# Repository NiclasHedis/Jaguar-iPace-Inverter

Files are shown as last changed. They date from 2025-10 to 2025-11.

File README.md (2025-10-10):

# Jaguar-iPace-Inverter
Design of Opensource Logic boards to run the Jaguar iPace Inverter and Motors.

PCB Designs in Kicad 9 format.

Front inverter used in the iPace is acuallly a Vitesco EPF2.8+ :
https://vitesco-technologies.com/en/Home/Solutions/Products/High-Voltage-Inverter-(EPF2-8-)-en

Reverse engineering thread on the openinverter forum :
https://openinverter.org/forum/viewtopic.php?f=23&t=1210

Videos :
https://youtu.be/Kg5qWuOF9P8

10/10/25 : Add prelim front drive unit V1 board design (work in progress).

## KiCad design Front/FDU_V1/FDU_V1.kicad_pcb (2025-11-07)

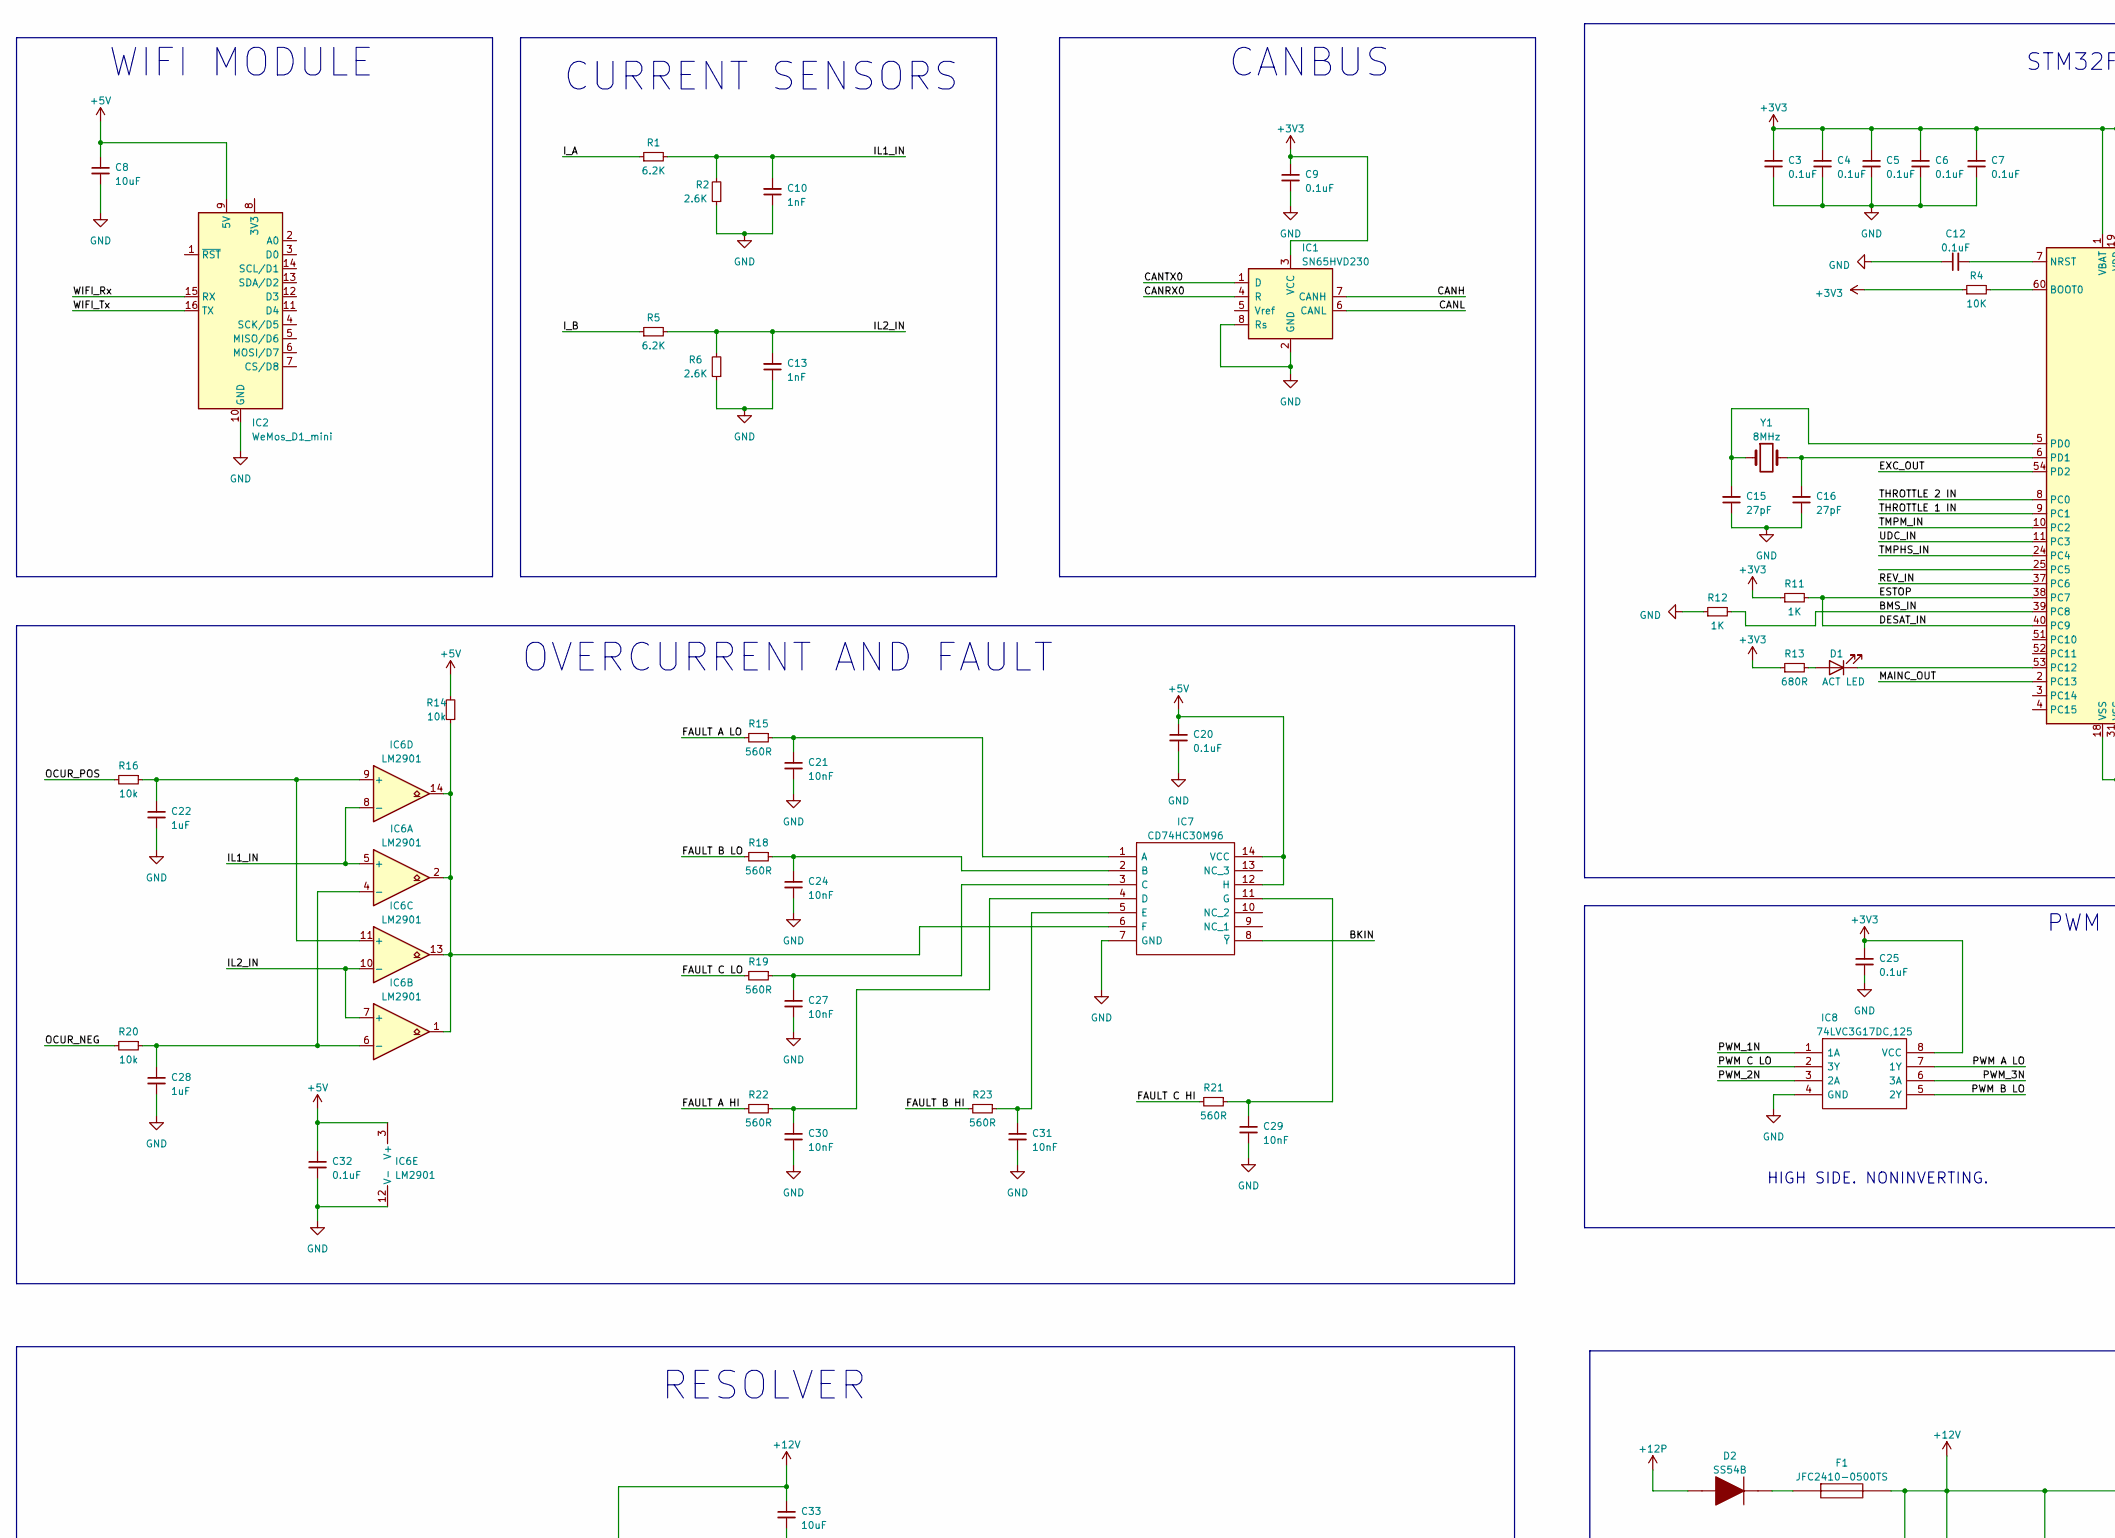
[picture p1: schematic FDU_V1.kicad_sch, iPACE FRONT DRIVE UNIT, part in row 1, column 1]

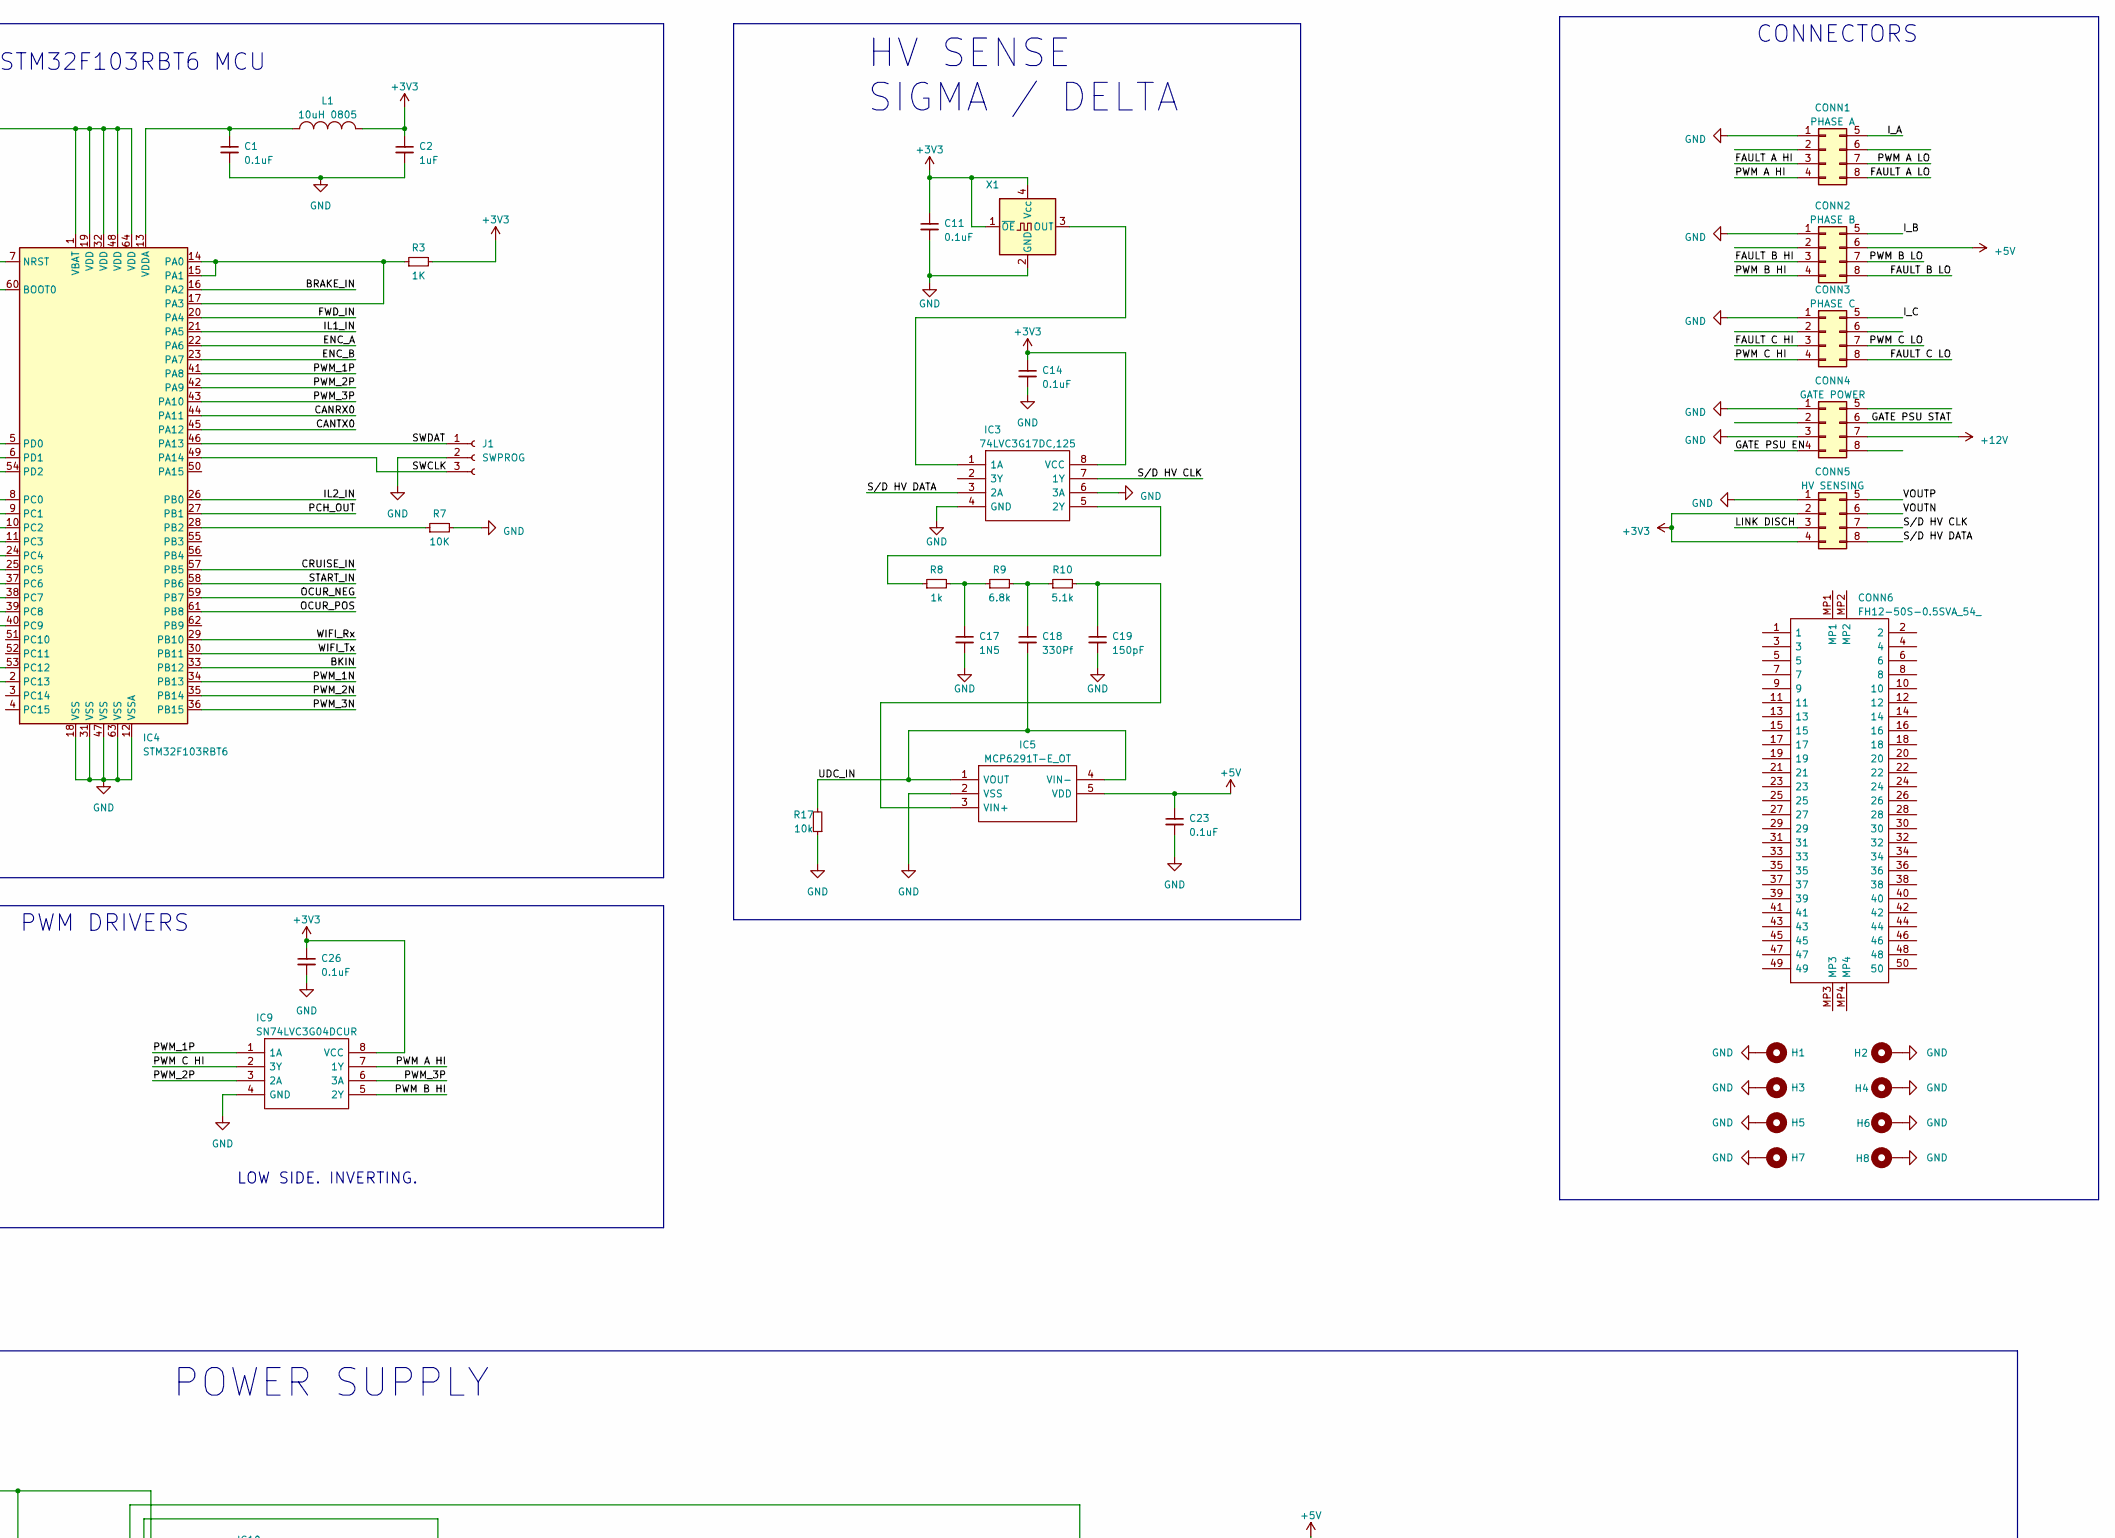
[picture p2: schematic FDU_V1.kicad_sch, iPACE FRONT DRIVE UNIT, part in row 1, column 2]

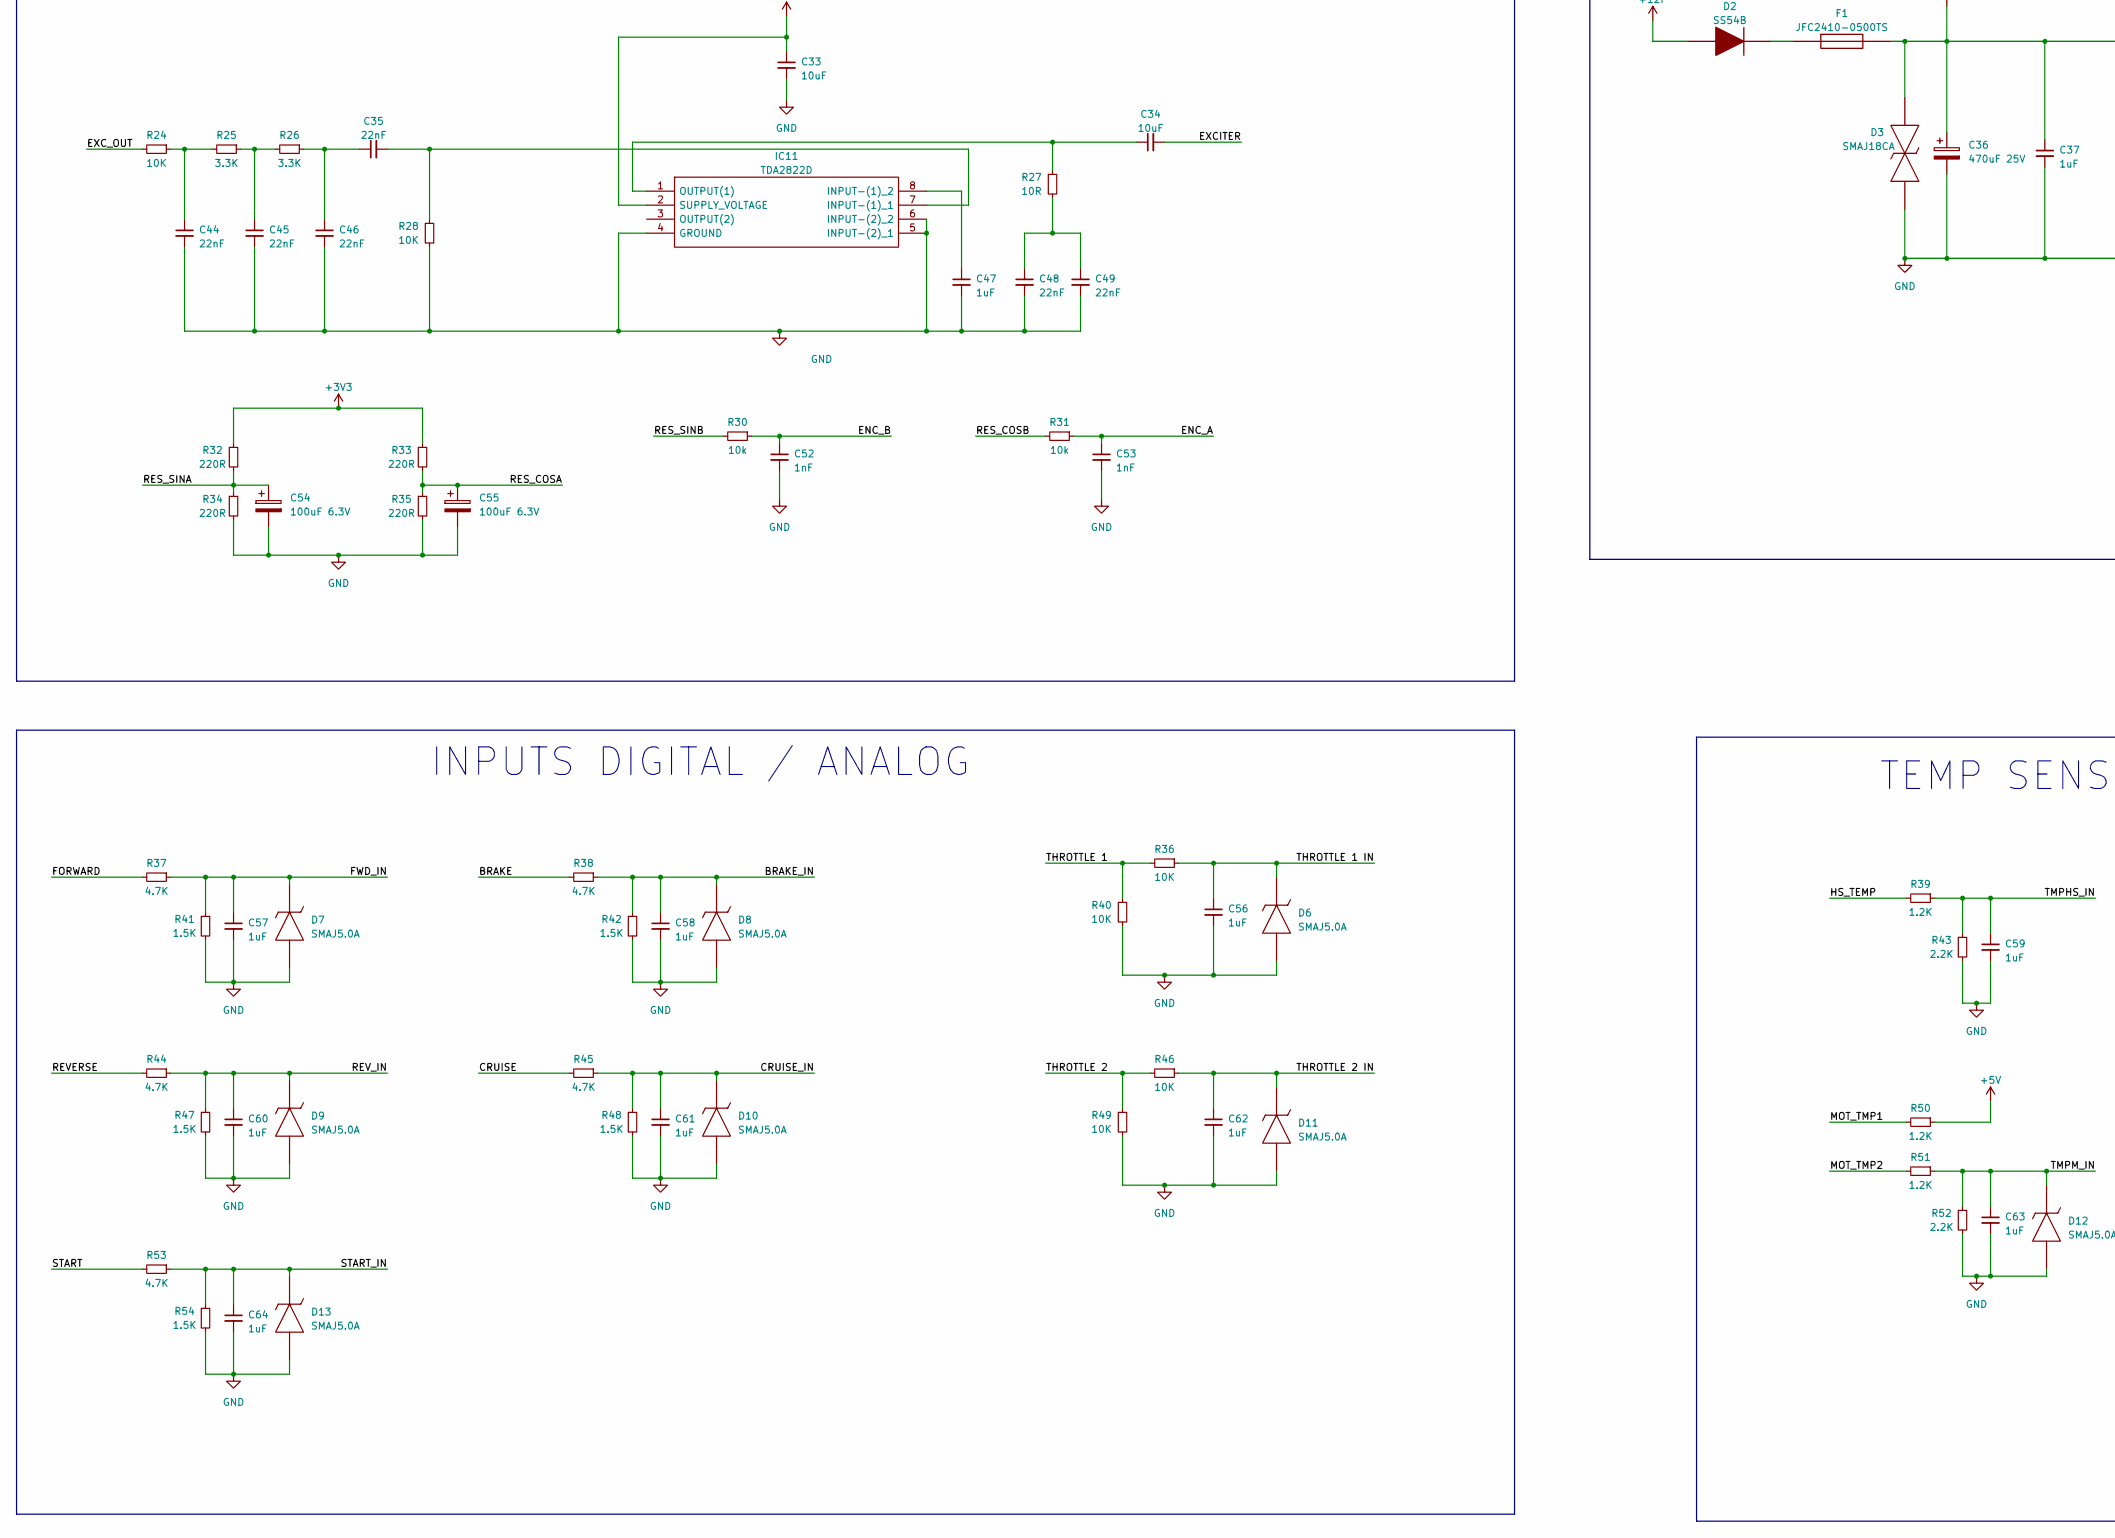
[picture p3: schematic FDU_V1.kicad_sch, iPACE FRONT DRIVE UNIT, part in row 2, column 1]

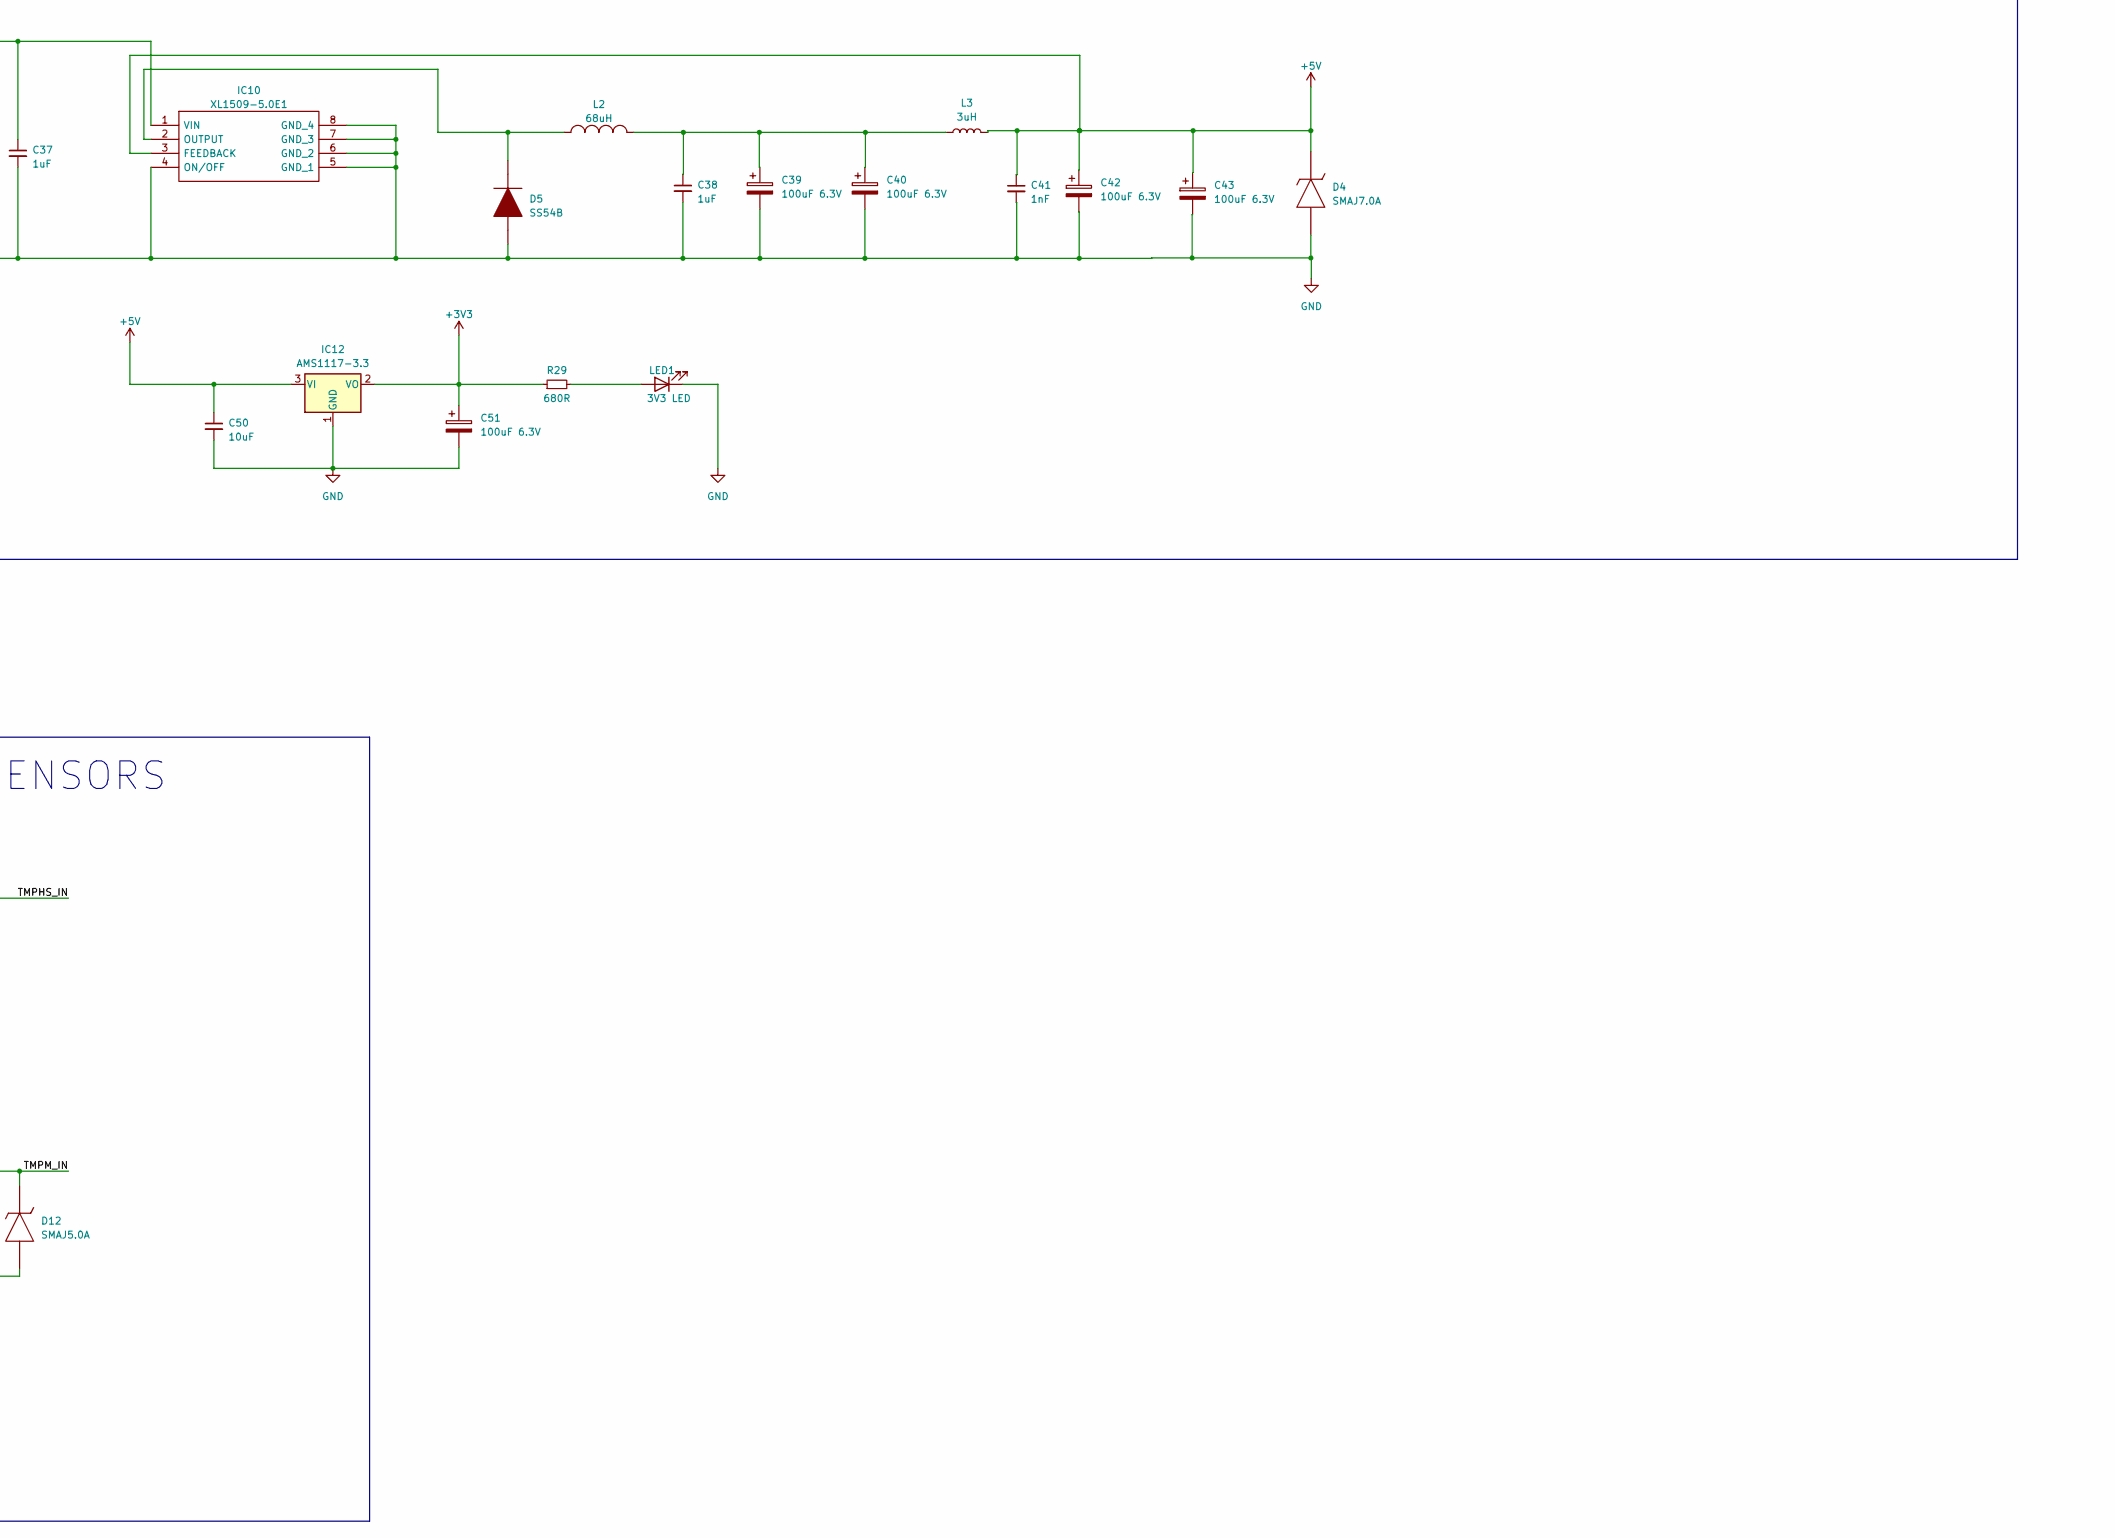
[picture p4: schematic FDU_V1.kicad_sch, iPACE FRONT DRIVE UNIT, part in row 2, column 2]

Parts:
C1, C3, C4, C5, C6, C7, C9, C11, C12, C14, C20, C23, C25, C26, C32: 0.1uF; C_0805_2012Metric
C2, C22, C28, C37, C38, C47, C56, C57, C58, C59, C60, C61, C62, C63, C64: 1uF; C_0805_2012Metric
C8, C33, C34, C50: 10uF; C_0805_2012Metric
C10, C13, C41, C52, C53: 1nF; C_0805_2012Metric
C15, C16: 27pF; C_0805_2012Metric
C17: 1N5; C_0805_2012Metric
C18: 330Pf; C_0805_2012Metric
C19: 150pF; C_0805_2012Metric
C21, C24, C27, C29, C30, C31: 10nF; C_0805_2012Metric
C35, C44, C45, C46, C48, C49: 22nF; C_0805_2012Metric
C36: 470uF 25V; CP_Elec_10x10
C39, C40, C42, C43, C51, C54, C55: 100uF 6.3V; CP_EIA-3528-15_AVX-H
CONN1: PHASE A; PinHeader_2x04_P2.54mm_Vertical
CONN2: PHASE B; PinHeader_2x04_P2.54mm_Vertical
CONN3: PHASE C; PinHeader_2x04_P2.54mm_Vertical
CONN4: GATE POWER; PinHeader_2x04_P2.54mm_Vertical
CONN5: HV SENSING; PinHeader_2x04_P2.54mm_Vertical
CONN6: FH12-50S-0.5SVA_54_; FH1250S05SVA54; Manufacturer_Part_Number FH12-50S-0.5SVA(54); Mouser Part Number 798-FH1250S0.5SVA54
D1: ACT LED; LED_0805_2012Metric
D2, D5: SS54B; DIOM5336X244N; Manufacturer_Part_Number SS54B
D3: SMAJ18CA; DIONM5127X229N; Manufacturer_Part_Number SMAJ18CA; Mouser Part Number 652-SMAJ18CA
D4: SMAJ7.0A; DIOM5026X229N; Manufacturer_Part_Number SMAJ7.0A; Mouser Part Number 576-SMAJ7.0A
D6, D7, D8, D9, D10, D11, D12, D13: SMAJ5.0A; DIOM5127X229N; Manufacturer_Part_Number SMAJ5.0A; Mouser Part Number 78-SMAJ5.0A
F1: JFC2410-0500TS; FUSC6126X280N; Manufacturer_Part_Number JFC2410-0500TS
H1: MountingHole; MountingHole_8.4mm_M8_Pad_Via
H2, H3, H4, H5, H6, H7, H8: MountingHole; MountingHole_8mm_ipace
IC1: SN65HVD230; SOIC-8_3.9x4.9mm_P1.27mm
IC2: WeMos_D1_mini; WEMOS_D1_mini_light
IC3, IC8: 74LVC3G17DC,125; SOP50P310X100-8N; Manufacturer_Part_Number 74LVC3G17DC,125; Mouser Part Number 771-LVC3G17DC125
IC4: STM32F103RBT6; LQFP-64_10x10mm_P0.5mm
IC5: MCP6291T-E_OT; SOT95P280X145-5N; Manufacturer_Part_Number MCP6291T-E/OT; Mouser Part Number 579-MCP6291T-E/OT
IC6: LM2901; SOIC-14_3.9x8.7mm_P1.27mm
IC7: CD74HC30M96; SOIC127P600X175-14N; Manufacturer_Part_Number CD74HC30M96; Mouser Part Number 595-CD74HC30M96
IC9: SN74LVC3G04DCUR; SOP50P310X90-8N; Manufacturer_Part_Number SN74LVC3G04DCUR; Mouser Part Number 595-SN74LVC3G04DCUR
IC10: XL1509-5.0E1; SOIC127P600X175-8N; Manufacturer_Part_Number XL1509-5.0E1
IC11: TDA2822D; SOIC127P600X175-8N; Manufacturer_Part_Number TDA2822D; Mouser Part Number 511-TDA2822D
IC12: AMS1117-3.3; SOT-223-3_TabPin2
J1: SWPROG; PinHeader_1x03_P2.54mm_Vertical
L1: 10uH 0805; L_0805_2012Metric
L2: 68uH; L_12x12mm_H8mm
L3: 3uH; L_10.4x10.4_H4.8
LED1: 3V3 LED; LED_0805_2012Metric
R1, R5: 6.2K; R_0805_2012Metric
R2, R6: 2.6K; R_0805_2012Metric
R3, R11, R12: 1K; R_0805_2012Metric
R4, R7, R24, R28, R36, R40, R46, R49: 10K; R_0805_2012Metric
R8: 1k; R_0805_2012Metric
R9: 6.8k; R_0805_2012Metric
R10: 5.1k; R_0805_2012Metric
R13, R29: 680R; R_0805_2012Metric
R14, R16, R17, R20, R30, R31: 10k; R_0805_2012Metric
R15, R18, R19, R21, R22, R23: 560R; R_0805_2012Metric
R25, R26: 3.3K; R_0805_2012Metric
R27: 10R; R_0805_2012Metric
R32, R33, R34, R35: 220R; R_0805_2012Metric
R37, R38, R44, R45, R53: 4.7K; R_0805_2012Metric
R39, R50, R51: 1.2K; R_0805_2012Metric
R41, R42, R47, R48, R54: 1.5K; R_0805_2012Metric
R43, R52: 2.2K; R_0805_2012Metric
X1: S3D4.000000B20F30T; Oscillator_SMD_EuroQuartz_XO32-4Pin_3.2x2.5mm
Y1: 8MHz; Crystal_SMD_5032-2Pin_5.0x3.2mm

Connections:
+3V3: C2.1, C3.1, C4.1, C5.1, C6.1, C7.1, C9.1, C11.1, C14.1, C25.1, C26.1, C51.1, CONN5.2, CONN5.4, IC1.3 (VCC), IC3.8 (VCC), IC4.1 (VBAT), IC4.19 (VDD), IC4.32 (VDD), IC4.48 (VDD), IC4.64 (VDD), IC8.8 (VCC), IC9.8 (VCC), IC12.2 (VO), L1.2, R3.2, R4.1, R11.1, R13.1, R29.1, R32.1, R33.1, X1.1 (~OE), X1.4 (Vcc)
+5V: C8.1, C20.1, C23.1, C32.1, C41.1, C42.1, C43.1, C50.1, CONN2.6, D4.1, IC2.9 (5V), IC5.5 (VDD), IC6.3 (V+), IC7.12 (H), IC7.14 (VCC), IC10.3 (FEEDBACK), IC12.3 (VI), L3.2, R14.2, R50.1; also elsewhere on the board
+12P: CONN6.28, CONN6.29, CONN6.30, CONN6.31, CONN6.32, CONN6.33, CONN6.34, CONN6.35, CONN6.36, CONN6.37, CONN6.38, CONN6.39, CONN6.40, CONN6.41, CONN6.42, CONN6.43, CONN6.44, CONN6.45, CONN6.46, CONN6.47, CONN6.48, CONN6.49, CONN6.50, D2.2
+12V: C33.1, C36.1, C37.1, CONN4.7, D3.1, F1.2, IC10.1 (VIN), IC11.2 (SUPPLY_VOLTAGE)
/BKIN: IC4.33 (PB12), IC7.8 (~Y)
/BMS_IN: IC4.39 (PC8), R12.2
/BRAKE: CONN6.14, R38.2
/BRAKE_IN: C58.1, D8.1, IC4.16 (PA2), R38.1, R42.1
/CANH: CONN6.1, IC1.7 (CANH)
/CANL: CONN6.2, IC1.6 (CANL)
/CANRX0: IC1.4 (R), IC4.44 (PA11)
/CANTX0: IC1.1 (D), IC4.45 (PA12)
/CRUISE: CONN6.22, R45.2
/CRUISE_IN: C61.1, D10.1, IC4.57 (PB5), R45.1, R48.1
/DESAT_IN: IC4.38 (PC7), IC4.40 (PC9), R11.2
/ENC_A: C53.1, IC4.22 (PA6), R31.1
/ENC_B: C52.1, IC4.23 (PA7), R30.1
/EXCA: C34.2, CONN6.17
/EXCB: CONN6.18; also elsewhere on the board
/EXC_OUT: IC4.54 (PD2), R24.2
/FAULT A HI: CONN1.3, R22.2
/FAULT A LO: CONN1.8, R15.2
/FAULT B HI: CONN2.3, R23.2
/FAULT B LO: CONN2.8, R18.2
/FAULT C HI: CONN3.3, R21.2
/FAULT C LO: CONN3.8, R19.2
/FORWARD: CONN6.7, R37.2
/FWD_IN: C57.1, D7.1, IC4.20 (PA4), R37.1, R41.1
/GATE PSU EN: CONN4.4
/GATE PSU STAT: CONN4.6
/HS_TEMP: R39.2
/IL1_IN: C10.2, IC4.21 (PA5), IC6.5 (+), IC6.8 (-), R1.2, R2.2
/IL2_IN: C13.2, IC4.26 (PB0), IC6.7 (+), IC6.10 (-), R5.2, R6.2
/I_A: CONN1.5, R1.1
/I_B: CONN2.5, R5.1
/I_C: CONN3.5
/LINK DISCH: CONN5.3
/MAINC_OUT: IC4.2 (PC13)
/MOT_TMP1_1: CONN6.9, R50.2
/MOT_TMP1_2: CONN6.10, R51.2
/MOT_TMP2_1: CONN6.11; also elsewhere on the board
/MOT_TMP2_2: CONN6.12; also elsewhere on the board
/OCUR_NEG: IC4.59 (PB7), R20.2
/OCUR_POS: IC4.61 (PB8), R16.2
/PCH_OUT: IC4.27 (PB1)
/PWM A HI: CONN1.4, IC9.7 (1Y)
/PWM A LO: CONN1.7, IC8.7 (1Y)
/PWM B HI: CONN2.4, IC9.5 (2Y)
/PWM B LO: CONN2.7, IC8.5 (2Y)
/PWM C HI: CONN3.4, IC9.2 (3Y)
/PWM C LO: CONN3.7, IC8.2 (3Y)
/PWM_1N: IC4.34 (PB13), IC8.1 (1A)
/PWM_1P: IC4.41 (PA8), IC9.1 (1A)
/PWM_2N: IC4.35 (PB14), IC8.3 (2A)
/PWM_2P: IC4.42 (PA9), IC9.3 (2A)
/PWM_3N: IC4.36 (PB15), IC8.6 (3A)
/PWM_3P: IC4.43 (PA10), IC9.6 (3A)
/RES_COSA: C55.1, CONN6.21, R33.2, R35.1
/RES_COSB: CONN6.20, R31.2
/RES_SINA: C54.1, CONN6.23, R32.2, R34.1
/RES_SINB: CONN6.24, R30.2
/REVERSE: CONN6.8, R44.2
/REV_IN: C60.1, D9.1, IC4.37 (PC6), R44.1, R47.1
/START: CONN6.3, R53.2
/START_IN: C64.1, D13.1, IC4.58 (PB6), R53.1, R54.1
/SWCLK: IC4.49 (PA14), J1.3
/SWDAT: IC4.46 (PA13), J1.1
/S/D HV CLK: CONN5.7, IC3.7 (1Y)
/S/D HV DATA: CONN5.8, IC3.3 (2A)
/THROTTLE 1: CONN6.15, R36.2, R40.1
/THROTTLE 1 IN: C56.1, D6.1, IC4.9 (PC1), R36.1
/THROTTLE 2: CONN6.16, R46.2, R49.1
/THROTTLE 2 IN: C62.1, D11.1, IC4.8 (PC0), R46.1
/TMPHS_IN: C59.1, IC4.24 (PC4), R39.1, R43.1
/UDC_IN: C18.2, IC4.11 (PC3), IC5.1 (VOUT), IC5.4 (VIN-), R17.2
/VOUTN: CONN5.6
/VOUTP: CONN5.5
/WIFI_Rx: IC2.15 (RX), IC4.29 (PB10)
/WIFI_Tx: IC2.16 (TX), IC4.30 (PB11)
/WTR_TMP1: CONN6.5; also elsewhere on the board
/WTR_TMP2: CONN6.6; also elsewhere on the board
GND: C1.2, C2.2, C3.2, C4.2, C5.2, C6.2, C7.2, C8.2, C9.2, C10.1, C11.2, C12.1, C13.1, C14.2, C15.1, C16.1, C17.2, C19.2, C20.2, C21.2, C22.2, C23.2, C24.2, C25.2, C26.2, C27.2, C28.2, C29.2, C30.2, C31.2, C32.2, C33.2, C36.2, C37.2, C38.2, C39.2, C40.2, C41.2, C42.2, C43.2, C44.2, C45.2, C46.2, C47.2, C48.2, C49.2, C50.2, C51.2, C52.2, C53.2, C54.2, C55.2, C56.2, C57.2, C58.2, C59.2, C60.2, C61.2, C62.2, C63.2, C64.2, CONN1.1, CONN2.1, CONN3.1, CONN4.1, CONN4.3, CONN5.1, D3.2, D4.2, D5.2, D6.2, D7.2, D8.2, D9.2, D10.2, D11.2, D12.2, D13.2, H1.1, H2.1, H3.1, H4.1, H5.1, H6.1, H7.1, H8.1, IC1.2 (GND), IC1.8 (Rs), IC2.10 (GND), IC3.4 (GND), IC3.6 (3A), IC4.12 (VSSA), IC4.18 (VSS), IC4.31 (VSS), IC4.47 (VSS), IC4.63 (VSS), IC5.2 (VSS), IC6.12 (V-), IC7.7 (GND), IC8.4 (GND), IC9.4 (GND), IC10.4 (ON/OFF), IC10.5 (GND_1), IC10.6 (GND_2), IC10.7 (GND_3), IC10.8 (GND_4), IC11.4 (GROUND), IC11.5 (INPUT-(2)_1), IC11.6 (INPUT-(2)_2), IC12.1 (GND), J1.2, LED1.1 (K), R2.1, R6.1, R7.2, R12.1, R17.1, R28.2, R34.2, R35.2, R40.2, R41.2, R42.2, R43.2, R47.2, R48.2, R49.2, R52.2, R54.2, X1.2 (GND); also elsewhere on the board
unnamed: C17.1, R8.2, R9.1
unnamed: C18.1, R9.2, R10.1
unnamed: C35.1, C46.1, R26.1
unnamed: C38.1, C39.1, C40.1, L2.2, L3.1
unnamed: C44.1, R24.1, R25.2
unnamed: C45.1, R25.1, R26.2
unnamed: C48.1, C49.1, R27.2
unnamed: D1.2 (A), R13.2
unnamed: D1.1 (K), IC4.53 (PC12)
unnamed: D2.1, F1.1
unnamed: IC3.1 (1A), X1.3 (OUT)
unnamed: IC3.5 (2Y), R8.1
unnamed: IC4.60 (BOOT0), R4.2
unnamed: C12.2, IC4.7 (NRST)
unnamed: IC4.14 (PA0), IC4.15 (PA1), IC4.17 (PA3), R3.1
unnamed: IC4.28 (PB2), R7.1
unnamed: C15.2, IC4.5 (PD0), Y1.1
unnamed: C16.2, IC4.6 (PD1), Y1.2
unnamed: C1.1, IC4.13 (VDDA), L1.1
unnamed: C19.1, IC5.3 (VIN+), R10.2
unnamed: C28.1, IC6.4 (-), IC6.6 (-), R20.1
unnamed: C22.1, IC6.9 (+), IC6.11 (+), R16.1
unnamed: C21.1, IC7.1 (A), R15.1
unnamed: C24.1, IC7.2 (B), R18.1
unnamed: C27.1, IC7.3 (C), R19.1
unnamed: C30.1, IC7.4 (D), R22.1
unnamed: C31.1, IC7.5 (E), R23.1
unnamed: IC6.1, IC6.2, IC6.13, IC6.14, IC7.6 (F), R14.1
unnamed: C29.1, IC7.11 (G), R21.1
unnamed: D5.1, IC10.2 (OUTPUT), L2.1
unnamed: C35.2, IC11.7 (INPUT-(1)_1), R28.1
unnamed: C47.1, IC11.8 (INPUT-(1)_2)
unnamed: C34.1, IC11.1 (OUTPUT(1)), R27.1
unnamed: LED1.2 (A), R29.2

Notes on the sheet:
WIFI MODULE
PWM DRIVERS
POWER SUPPLY
CONNECTORS
CURRENT SENSORS
RESOLVER
OVERCURRENT AND FAULT
STM32F103RBT6 MCU
HIGH SIDE. NONINVERTING.
LOW SIDE. INVERTING.
HV SENSE SIGMA / DELTA
INPUTS DIGITAL / ANALOG
CANBUS
TEMP SENSORS

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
Board: 4 copper layers, 174 parts (0 on the bottom side), 108 nets, no tracks yet.

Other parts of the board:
C65, C66: 1uF; C_0805_2012Metric
R55, R56, R58, R60: 1.2K; R_0805_2012Metric
R57, R61: 2.2K; R_0805_2012Metric
R59: 0K; R_0805_2012Metric

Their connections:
+5V: R55.1, R58.1; also elsewhere on the board
/EXCB: R59.1; also elsewhere on the board
/MOT_TMP2_1: R58.2; also elsewhere on the board
/MOT_TMP2_2: R60.2; also elsewhere on the board
/TMPM2_IN: C66.1, R60.1, R61.1
/TMPWTR_IN: C65.1, R56.1, R57.1
/WTR_TMP1: R55.2; also elsewhere on the board
/WTR_TMP2: R56.2; also elsewhere on the board
GND: C65.2, C66.2, R57.2, R59.2, R61.2; also elsewhere on the board

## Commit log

2025-10-10 Add FDU V1 wip
    [FDU_V1.kicad_pcb, FDU_V1.kicad_sch]
2025-11-07 Continued work on both schematic and board placement.
    Schematic: Pinout added for external 28pin connector.
    PCB: Corrected board outline dimensions and all external dependencies. (holes, pin headers, ZIP connector)
    [FDU_V1.kicad_pcb]
2026-03-10 Changed microcontroller to 100pin
    [FDU_V1.kicad_sch]

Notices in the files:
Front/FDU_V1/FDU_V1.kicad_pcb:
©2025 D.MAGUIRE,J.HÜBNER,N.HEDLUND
